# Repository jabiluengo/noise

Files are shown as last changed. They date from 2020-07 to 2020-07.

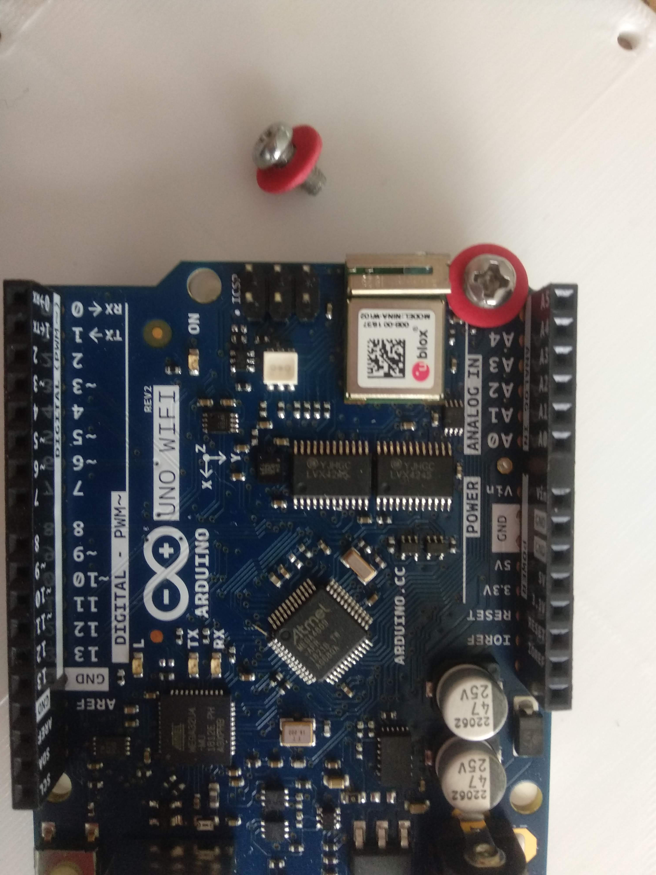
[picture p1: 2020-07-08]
photos/IMG_20200701_131713.jpg

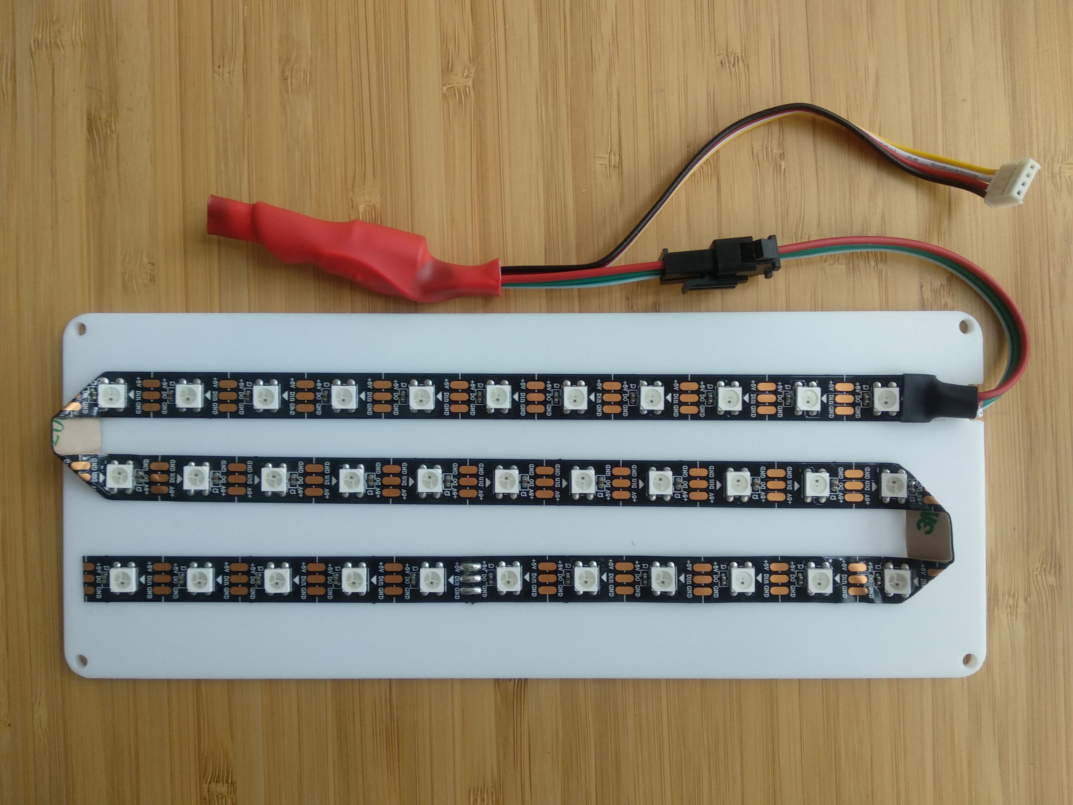
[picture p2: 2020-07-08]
photos/IMG_20200701_111953.jpg

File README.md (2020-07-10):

# NOISE
## SISTEMA DE ALERTA Y MONITORIZACIÓN DEL RUIDO EN UN AULA
La contaminación acústica el las aulas de secundaria es un problema que afecta directamente al rendimiento y al ambiente de la clase.
La idea es diseñar un sistema que alerta de los niveles de ruido a los propios alumnos y profesores y que puede ser monitorizado para poder estudiar las causas y posibles soluciones.
El dispositivo mediante un sistema visual (semáforo) alerta del nivel de ruido y además envía los valores en tiempo real a Thingspeak para su monitorización y posterior tratamiento.
Qué necesito:
- [Arduino Uno Wifi rev2](https://store.arduino.cc/arduino-uno-wifi-rev2)
- [Sparkfun Sound detector](https://www.sparkfun.com/products/12642)
- [Tira de LEDs RGB WS2811](https://www.amazon.es/gp/product/B01CDTEFAQ)
- [Grove Shield](https://www.seeedstudio.com/Base-Shield-V2.html)
- Alimentador de entre 7 y 12 V con conector tipo barrel
- Carcasa impresa en 3D (ver diseño en OpenScad)
- Cables y conectores Grove
- Conectore macho y hembra tipo barrel
- Programa de Arduino (ver Arduino)
- Cuenta en Thingspeak
## Ayuda
- Fotos del montaje en la carpeta correspondiente.
- [Vídeo del funcionamiento](https://www.youtube.com/watch?v=zTPq-qi6xA0)

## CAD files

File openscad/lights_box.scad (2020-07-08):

/*
By Jabi Luengo (@jabiluengo)
Licence Creative commons atribution & share alike.
Bassed in https://github.com/gregmarra/project_box

The MIT License (MIT)

Copyright (c) 2014 Greg Marra

Permission is hereby granted, free of charge, to any person obtaining a copy
of this software and associated documentation files (the "Software"), to deal
in the Software without restriction, including without limitation the rights
to use, copy, modify, merge, publish, distribute, sublicense, and/or sell
copies of the Software, and to permit persons to whom the Software is
furnished to do so, subject to the following conditions:

The above copyright notice and this permission notice shall be included in all
copies or substantial portions of the Software.
*/
enclosure_inner_length = 200;
enclosure_inner_width = 80;
enclosure_inner_depth = 20;
second_depth = 40;

enclosure_thickness = 3;
bass_thinkness = 0.50;

cover_thickness = 3;

strip_w = 8;
strip_d = 1.5;
strip_n = 3;

wire_hole_x = 8;
wire_hole_y = 6;
wire_hole_z = 2;


part = "cover"; // [enclosure:Enclosure, cover:Cover, leds_cover:Leds Cover]

print_part();

module print_part() {
	if (part == "enclosure") {
		box2(enclosure_inner_length,enclosure_inner_width,enclosure_inner_depth,enclosure_thickness,enclosure_thickness/2-0.10,cover_thickness,bass_thinkness,second_depth);
	} else if (part == "cover") {
		lid2(enclosure_inner_length,enclosure_inner_width,enclosure_inner_depth+second_depth,enclosure_thickness,enclosure_thickness/2+0.10,cover_thickness);
    } else if (part == "leds_cover") {
		lid(enclosure_inner_length,enclosure_inner_width,enclosure_inner_depth,enclosure_thickness,enclosure_thickness/2+0.10,cover_thickness,strip_w,strip_d,strip_n,wire_hole_x,wire_hole_y,wire_hole_z);
    } else if (part == "cover") {
		lid2(enclosure_inner_length,enclosure_inner_width,enclosure_inner_depth,enclosure_thickness,enclosure_thickness/2+0.10,cover_thickness);	
        }
}

module screws(in_x, in_y, in_z, shell) {

	sx = in_x/2 - 4;
	sy = in_y/2 - 4;
	sh = shell + in_z - 12;
	nh = shell + in_z - 4;

	translate([0,0,0]) {
		translate([sx , sy, sh]) cylinder(r=1.5, h = 15, $fn=32);
		translate([sx , -sy, sh ]) cylinder(r=1.5, h = 15, $fn=32);
		translate([-sx , sy, sh ]) cylinder(r=1.5, h = 15, $fn=32);
		translate([-sx , -sy, sh ]) cylinder(r=1.5, h = 15, $fn=32);
	
	
		translate([-sx , -sy, nh ]) rotate([0,0,-45]) 
			translate([-5.75/2, -5.6/2, -0.7]) cube ([5.75, 10, 2.8]);
		translate([sx , -sy, nh ]) rotate([0,0,45]) 
			translate([-5.75/2, -5.6/2, -0.7]) cube ([5.75, 10, 2.8]);
		translate([sx , sy, nh ]) rotate([0,0,90+45]) 
			translate([-5.75/2, -5.6/2, -0.7]) cube ([5.75, 10, 2.8]);
		translate([-sx , sy, nh ]) rotate([0,0,-90-45]) 
			translate([-5.75/2, -5.6/2, -0.7]) cube ([5.75, 10, 2.8]);
	}
}
module logo(height,size) {
    linear_extrude(height = height) {
        scale(size)
        import("noise.svg");
    }
}
module bottom(in_x, in_y, in_z, shell,thin) {
    translate([0,0,shell-thin])
	hull() {
   	 	translate([-in_x/2+shell, -in_y/2+shell, 0]) cylinder(r=shell*2,h=thin, $fn=32);
		translate([+in_x/2-shell, -in_y/2+shell, 0]) cylinder(r=shell*2,h=thin, $fn=32);
		translate([+in_x/2-shell, in_y/2-shell, 0]) cylinder(r=shell*2,h=thin, $fn=32);
		translate([-in_x/2+shell, in_y/2-shell, 0]) cylinder(r=shell*2,h=thin, $fn=32);
	}
    if (part == "enclosure") translate ([in_x/2-50,28,thin+shell]) rotate([0,0,-90]) logo(2,0.15);
}

module sides(in_x, in_y, in_z, shell) {
	translate([0,0,shell])
	difference() {
		hull() {
	   	 	translate([-in_x/2+shell, -in_y/2+shell, 0]) cylinder(r=shell*2,h=in_z, $fn=32);
			translate([+in_x/2-shell, -in_y/2+shell, 0]) cylinder(r=shell*2,h=in_z, $fn=32);
			translate([+in_x/2-shell, in_y/2-shell, 0]) cylinder(r=shell*2,h=in_z, $fn=32);
			translate([-in_x/2+shell, in_y/2-shell, 0]) cylinder(r=shell*2,h=in_z, $fn=32);
		}
	
		hull() {
	   	 	translate([-in_x/2+shell, -in_y/2+shell, 0]) cylinder(r=shell,h=in_z+1, $fn=32);
			translate([+in_x/2-shell, -in_y/2+shell, 0]) cylinder(r=shell,h=in_z+1, $fn=32);
			translate([+in_x/2-shell, in_y/2-shell, 0]) cylinder(r=shell,h=in_z+1, $fn=32);
			translate([-in_x/2+shell, in_y/2-shell, 0]) cylinder(r=shell,h=in_z+1, $fn=32);
		}
	}
	
	intersection() {
		translate([-in_x/2, -in_y/2, shell]) cube([in_x, in_y, in_z+2]);
		union() {
			translate([-in_x/2 , -in_y/2,shell + in_z -6]) cylinder(r=9, h = 6, $fn=64);
			translate([-in_x/2 , -in_y/2,shell + in_z -10]) cylinder(r1=3, r2=9, h = 4, $fn=64);
		
			translate([in_x/2 , -in_y/2, shell + in_z -6]) cylinder(r=9, h = 6, $fn=64);
			translate([in_x/2 , -in_y/2, shell + in_z -10]) cylinder(r1=3, r2=9, h = 4, $fn=64);
		
			translate([in_x/2 , in_y/2,  shell + in_z -6]) cylinder(r=9, h = 6, $fn=64);
			translate([in_x/2 , in_y/2,  shell + in_z -10]) cylinder(r1=3, r2=9, h = 4, $fn=64);
		
			translate([-in_x/2 , in_y/2, shell + in_z -6]) cylinder(r=9, h = 6, $fn=64);
			translate([-in_x/2 , in_y/2, shell + in_z -10]) cylinder(r1=3, r2=9, h = 4, $fn=64);
		}
	}
}

module lid_top_lip2(in_x, in_y, in_z, shell, top_lip, top_thickness) {

	cxm = -in_x/2 - (shell-top_lip);
	cxp = in_x/2 + (shell-top_lip);
	cym = -in_y/2 - (shell-top_lip);
	cyp = in_y/2 + (shell-top_lip);

	translate([0,0,shell+in_z])

	difference() {
	
		hull() {
	   	 	translate([-in_x/2+shell, -in_y/2+shell, 0]) cylinder(r=shell*2,h=top_thickness, $fn=32);
			translate([+in_x/2-shell, -in_y/2+shell, 0]) cylinder(r=shell*2,h=top_thickness, $fn=32);
			translate([+in_x/2-shell, in_y/2-shell, 0]) cylinder(r=shell*2,h=top_thickness, $fn=32);
			translate([-in_x/2+shell, in_y/2-shell, 0]) cylinder(r=shell*2,h=top_thickness, $fn=32);
		}
	
		
		translate([0, 0, -1]) linear_extrude(height = top_thickness + 2) polygon(points = [
			[cxm+5, cym],
			[cxm, cym+5],
			[cxm, cyp-5],
			[cxm+5, cyp],
			[cxp-5, cyp],
			[cxp, cyp-5],
			[cxp, cym+5],
			[cxp-5, cym]]);
	}
}
module uno_holes(height = 6, cil_rad = 2.5, hole_rad = 1.3, z = 0) {
    rotate([180,0,0]) difference() {
        union() {
		translate(v = [14, 2.5, z]) {
			cylinder(h = height, r = cil_rad, center = true, $fn=36);
        }
		translate(v = [15.3, 50.7, z]) {
			cylinder(h = height, r = cil_rad, center = true, $fn=36);
        }
        translate(v = [66.1, 7.6, z]) {
			cylinder(h = height, r = cil_rad, center = true, $fn=36);
        }
        translate(v = [66.1, 35.5, z]) {
			cylinder(h = height, r = cil_rad, center = true, $fn=36);
        }
        }
        union() {
		translate(v = [14, 2.5, z]) {
			cylinder(h = height, r = hole_rad, center = true, $fn=36);
        }
		translate(v = [15.3, 50.7, z]) {
			cylinder(h = height, r = hole_rad, center = true, $fn=36);
        }
        translate(v = [66.1, 7.6, z]) {
			cylinder(h = height, r = hole_rad, center = true, $fn=36);
        }
        translate(v = [66.1, 35.5, z]) {
			cylinder(h = height, r = hole_rad, center = true, $fn=36);
        }
        }
        }
}
module sensor_holes(height = 6, cil_rad = 2.5, hole_rad = 1.3, z = 0) {
    difference() {
        union() {
		translate(v = [-40, -5, z]) {
			cylinder(h = height, r = cil_rad, center = true, $fn=36);
        }
		translate(v = [-40, 33, z]) {
			cylinder(h = height, r = cil_rad, center = true, $fn=36);
        }
        }
        union() {
		translate(v = [-40, -5, z]) {
			cylinder(h = height, r = hole_rad, center = true, $fn=36);
        }
		translate(v = [-40, 33, z]) {
			cylinder(h = height, r = hole_rad, center = true, $fn=36);
        }
        }
        }
}


module lid(in_x, in_y, in_z, shell, top_lip, top_thickness, w, d, n, wire_x, wire_y, wire_z) {
    difference() {
		translate([0, 0, in_z+shell]) bottom(in_x-2*shell-1, in_y-2*shell-1, in_z, shell,       thin=shell);
        screws(in_x, in_y, in_z-2*shell, 3*shell);
        translate([in_x/2-(shell/2), -in_y/3+7, in_z+shell]) cube([3*d,w,10], center=true);
} 
}
module lid2(in_x, in_y, in_z, shell, top_lip, top_thickness) {

	cxm = -in_x/2 - (shell-top_lip);
	cxp = in_x/2 + (shell-top_lip);
	cym = -in_y/2 - (shell-top_lip);
	cyp = in_y/2 + (shell-top_lip);	
    translate([0,25,in_z]) uno_holes();
    translate([0,-25,in_z]) sensor_holes();
	difference() {
		translate([0, 0, in_z+shell]) linear_extrude(height = top_thickness ) polygon(points = [
			[cxm+5, cym],
			[cxm, cym+5],
			[cxm, cyp-5],
			[cxm+5, cyp],
			[cxp-5, cyp],
			[cxp, cyp-5],
			[cxp, cym+5],
			[cxp-5, cym]]);
	
			screws(in_x, in_y, in_z, shell);
        translate([in_x/2.3, 0, in_z+shell-1]) cylinder(h = top_thickness*2, r = 2, center = false, $fn=36);
        translate([in_x/2.3-8, 0, in_z+shell-1]) cylinder(h = top_thickness*2, r = 2, center = false, $fn=36);
        translate([in_x/2.3-4, 0, in_z+shell-1]) cube([8,4,top_thickness*3], center=true);
	}
       
}
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

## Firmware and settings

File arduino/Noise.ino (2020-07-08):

/*
Noise: Sistema de alerta y monitorización del ruido en un aula
Captura el nivel de presión sonora mediante un sensor de sonido analógico y lo muestra visualmente con una tira de leds con los colores de un semáforo.
A la vez envía cada cierto tiempo el dato de presión sonora a Thingspeak para su visualización y posterior tratamiento.
Las líneas de código comentadas corresponden a la monitorización serie que ralentizan el programa. Quitar los comentarios para depurar el código
Creado por Jabi Luengo
*/
 
// Librerías utilizadas
#include "arduino_secrets.h"
#include <TimeAlarms.h>
#include "math.h"
#include <Smoothed.h> 	// Created by Matthew Fryer
#include "ThingSpeak.h"
#include <WiFiNINA.h>
#include <Adafruit_NeoPixel.h>


// Definiciones de la parte de conexión y envío de datos a Thingspeak
char ssid[] = SECRET_SSID;    //  your network SSID (name) 
char pass[] = SECRET_PASS;   // your network password
int keyIndex = 0;            // your network key Index number (needed only for WEP)
WiFiClient  client;
unsigned long myChannelNumber = SECRET_CHANNEL;
const char * myWriteAPIKey = SECRET_API;
const int thing_time = 5; // Cada cuántos segundos se envía el dato a Thingspeak


// Definiciones de la sensorización
#define SENSOR_PIN A1    // Pin de conexionado del sensor 
Smoothed <float> mySensor; // Objeto de tipo Smoothed donde se guarda el nivel sonoro suavizado
const int sanples = 100; // Cuántas muestras se utilizan en el suavizado
const int dBmin = 50; // Presión sonora mínima: equivale al verde puro en el semáforo
const int dBmax = 80; // Presión sonora máxima: equivale al rojo puro en el semáforo
const float vc = 20; // Variable para transformar la tensión obtenida por el sensor analógico en presión sonora
const float vm = 40; // Variable para transformar la tensión obtenida por el sensor analógico en presión sonora
float dB = dBmin;
const int delay_sanple = 2;


// Definiciones del control de LEDS
int led_i = 0;
#ifdef __AVR__
 #include <avr/power.h> // Required for 16 MHz Adafruit Trinket
#endif
#define LED_PIN 8// Pin utilizado para el control de la tira de Leds
#define LED_COUNT 35 // Cuántos Leds tiene la tira
Adafruit_NeoPixel pixels(LED_COUNT, LED_PIN, NEO_GRB + NEO_KHZ800);
// Argument 1 = Number of pixels in NeoPixel strip
// Argument 2 = Arduino pin number (most are valid)
// Argument 3 = Pixel type flags, add together as needed:
//   NEO_KHZ800  800 KHz bitstream (most NeoPixel products w/WS2812 LEDs)
//   NEO_KHZ400  400 KHz (classic 'v1' (not v2) FLORA pixels, WS2811 drivers)
//   NEO_GRB     Pixels are wired for GRB bitstream (most NeoPixel products)
//   NEO_RGB     Pixels are wired for RGB bitstream (v1 FLORA pixels, not v2)
//   NEO_RGBW    Pixels are wired for RGBW bitstream (NeoPixel RGBW products)


void ThingSpeak_alarm() // Alarma de envío de datos a Thingspeak
{
  // Connect or reconnect to WiFi
  if(WiFi.status() != WL_CONNECTED){
    //Serial.print("Attempting to connect to SSID: ");
    //Serial.println(SECRET_SSID);
    while(WiFi.status() != WL_CONNECTED){
      WiFi.begin(ssid, pass); // Connect to WPA/WPA2 network. Change this line if using open or WEP network
      //Serial.print(".");
      delay(5000);     
    } 
    //Serial.println("\nConnected.");
  }
  // Write to ThingSpeak. There are up to 8 fields in a channel, allowing you to store up to 8 different
  // pieces of information in a channel.  Here, we write to field 1.
  int x = ThingSpeak.writeField(myChannelNumber, 1, dB, myWriteAPIKey);
  //if(x == 200){
  //  Serial.println("Channel update successful.");
  //}
  //else{
  //  Serial.println("Problem updating channel. HTTP error code " + String(x));
  //}

}

long mapf(float x, float in_min, float in_max, float out_min, float out_max){ // Función de mapeo de variables flotantes
  return (x - in_min) * (out_max - out_min) / (in_max - in_min) + out_min;
  }


void setup() {
  
  // These lines are specifically to support the Adafruit Trinket 5V 16 MHz.
  // Any other board, you can remove this part (but no harm leaving it):
  #if defined(__AVR_ATtiny85__) && (F_CPU == 16000000)
  clock_prescale_set(clock_div_1);
  #endif

  pixels.begin();
  Serial.begin(9600);
	mySensor.begin(SMOOTHED_EXPONENTIAL, sanples); // Utilizamos el suavizado con el filtro lineal recursivo exponencial
  mySensor.clear();
  
  Alarm.timerRepeat(thing_time, ThingSpeak_alarm);

  if (WiFi.status() == WL_NO_MODULE) {
    //Serial.println("Communication with WiFi module failed!");
    // don't continue
    while (true);
  }

  String fv = WiFi.firmwareVersion();
  if (fv != "1.0.0") {
    //Serial.println("Please upgrade the firmware");
  }
    
  ThingSpeak.begin(client);  //Initialize ThingSpeak
}



void loop() {

   
  float currentSensorValue = analogRead(SENSOR_PIN); // Leemos el valor del sensor analógico
  mySensor.add(currentSensorValue); // Añadimos el valor al objeto
    
  float smoothedSensorValueExp = mySensor.get(); // Obtenemos suavizado exponencial de las muestras
  if (smoothedSensorValueExp > vc) dB=20*log10(smoothedSensorValueExp-vc)+vm; // Cálculo de la presión sonora mediante fórmula logarítmica
  //else dB=vc;
  float show=dB;
  if (dB > dBmax) show=dBmax; // Si la presión sonora calculada excede la máxima, la recortamos (color rojo)
  if (dB < dBmin) show=dBmin; // Si la presión sonora calculada excede la mínima, la recortamos (color verde)
    
  float mapedsmooth = mapf(show, dBmin, dBmax, 21845, 0); // Mapeamos el valor de presión sonora al intervalo de colores verde-rojo de la paleta HSV. El verde corresponde al valor 21845 y el rojo al valor 0
  Serial.print(smoothedSensorValueExp);
  Serial.print("  ");
  Serial.print(dB);
  Serial.print("  ");
  Serial.println(mapedsmooth);
  uint32_t rgbcolor = pixels.ColorHSV(mapedsmooth);

  if ((led_i != 11) && (led_i != 23)){ // Los pixels 11 y 23 no los utilizamos por el doblado de la tira
    pixels.setPixelColor(led_i, rgbcolor); //encendemos cada pixel con el valor suavizado actual obteniendo un efecto visual
    pixels.show();
    }
  if (led_i >= 34) led_i = 0;
    else led_i++;
  
  // Si queremos utilizar el último valor guardado
  // float lastValueStoredExp = mySensor.getLast();

  Alarm.delay(delay_sanple); // Delay necesario para el funcionamiento de las Alarmas
}
